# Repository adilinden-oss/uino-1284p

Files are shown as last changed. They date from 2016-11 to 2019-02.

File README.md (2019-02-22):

## \*uino-1284p 

\*uino-1284p is an Arduino compatible platform based on the Atmel ATmega1284P-AU microcontroller.

### Licensing

This work is licensed under a Creative Commons Attribution-ShareAlike 3.0 Unported License, CC BY-SA.

You are free to copy, distribute and transmit the work. You must attribute the work in the manner specified by the author or licensor (but not in any way that suggests that they endorse you or your use of the work). you alter, transform, or build upon this work, you may distribute the resulting work only under the same or similar license to this one.  

Please refer to [http://creativecommons.org/licenses/by-sa/3.0/] for the license.

### Credit

The \*uino-1284p is derived from previous work done by:

- The Arduino team <http://arduino.cc/>

### Details

The \*uino-1284p board utilizes the ATmega1284P microcontroller. The main goal of this project is to be able to access more memory, both FLASH and RAM, while keeping the Arduino UNO compatible board size and I/O assignments.

The ATmega1284P provides 128k of FLASH and 16k of RAM. It has 10 more I/O pins then the ATmega328P. The additional I/O pins are brought out to a 5x2 header in a non-standard Arduino position. The extra header pins are :

        L1/D16  o|o  L2/D17
           D18  o|o  D19
           D20  o|o  D21
           D22  o|o  D23
        D24/A6  o|o  D25/A7

The design features a dedicated ATmega8U2 for USB connectivity. The circuit has been taken from the Arduino UNO but the TQFP-32 package was chosen for easy solderability.

Power supply input for the board is selected via a jumper. Power supply options are USB bus powered or unregulated DC input. An onboard LDO regulator will accept an unregulated input voltage between 6.4V and 15V.

### Arduino

The board is supported in Arduino IDE 1.6.x via the core files available at: [adilinden-oss/uino-arduino](https://github.com/adilinden-oss/uino-arduino)

To install clone uino-arduino into the hardware folder inside your Sketchbook folder. The board will then automagically appear in the Boards menu.

### Pin Mapping

```
*uino     ATmega1284p                     Function
A0  D26   32 - PA5 (PCINT5/ADC5)
A1  D27   33 - PA4 (PCINT4/ADC4)
A2  D28   34 - PA3 (PCINT3/ADC3)
A3  D29   35 - PA2 (PCINT2/ADC2)
A4  D30   36 - PA1 (PCINT1/ADC1)
A5  D31   37 - PA0 (PCINT0/ADC0)

D0        9  - PD0 (PCINT24/RXD0/T3)      UART RX0
D1        10 - PD1 (PCINT25/TXD0)         UART TX0
D2        11 - PD2 (PCINT26/RXD1/INT0)    IRQ2, UART RX1
D3        12 - PD3 (PCINT27/TXD1/INT1)    IRQ3, UART TX1
D4        13 - PD4 (PCINT28/XCK1/OC1B)    PWM
D5        14 - PD5 (PCINT29/OC1A)         PWM
D6        15 - PD6 (PCINT30/OC2B/ICP)     PWM
D7        16 - PD7 (PCINT31/OC2A)         PWM

D8        42 - PB2 (PCINT10/INT2/AIN0)  
D9        43 - PB3 (PCINT11/OC0A/AIN1)    PWM
D10       44 - PB4 (PCINT12/OC0B/SS)      PWM, SPI SS
D11       1  - PB5 (PCINT13/ICP3/MOSI)    SPI MOSI
D12       2  - PB6 (PCINT14/OC3A/MISO)    PWM, SPI MISO
D13       3  - PB7 (PCINT15/OC3B/SCK)     PWM, SPI SCK, LED

SCL D14   19 - PC0 (PCINT16/SCL)          SCL
SDA D15   20 - PC1 (PCINT17/SDA)          SDA
L1  D16   21 - PC2 (PCINT18/TCK)          L1
L2  D17   22 - PC3 (PCINT19/TMS)          L2

D18       23 - PC4 (PCINT20/TDO)
D19       24 - PC5 (PCINT21/TDI)
D20       25 - PC6 (PCINT22/TOSC1)
D21       26 - PC7 (PCINT23/TOSC2)
D22       40 - PB0 (PCINT8/T0/XCK0)
D23       41 - PB1 (PCINT9/T1/CLK0)
A6  D24   30 - PA7 (PCINT7/ADC7)
A7  D25   31 - PA6 (PCINT6/ADC6)
```

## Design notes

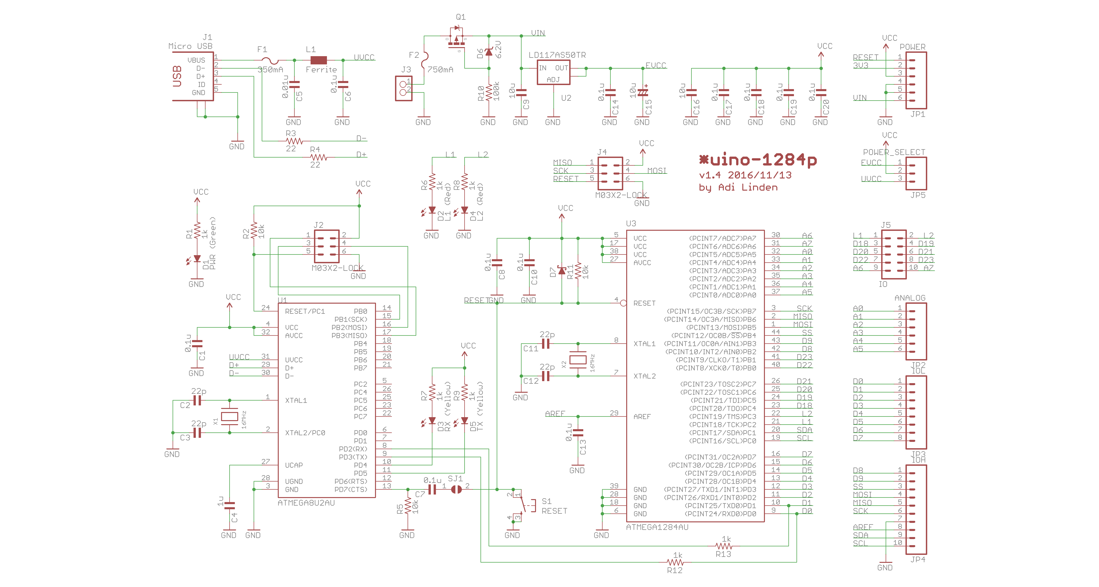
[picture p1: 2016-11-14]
uino-1284p-sch.png

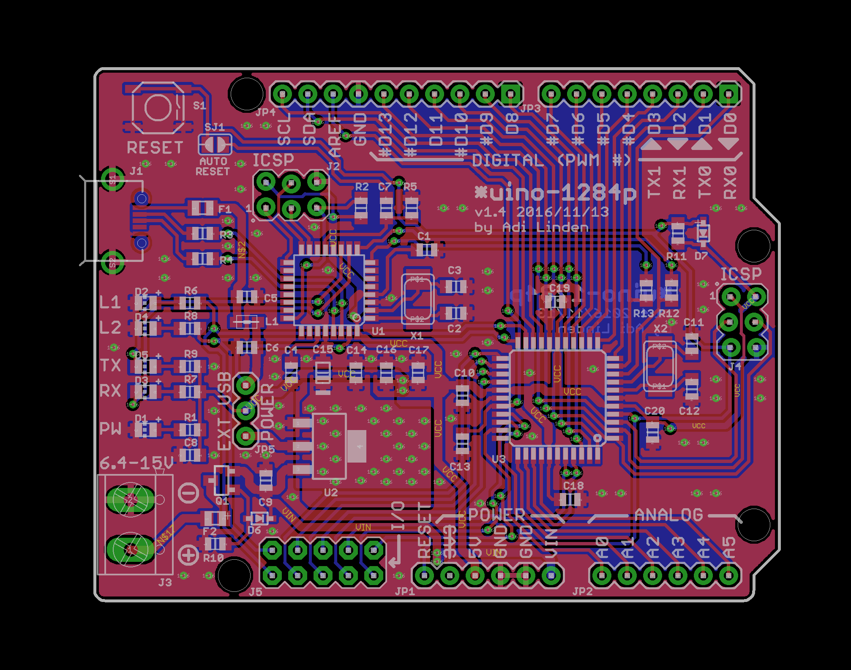
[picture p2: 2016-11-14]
uino-1284p-brd.png

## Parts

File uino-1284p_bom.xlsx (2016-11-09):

Part | Quantity | Value | Manufacturer Part Number | DigiKey Part Number | Package | Description
C1, C6, C7, C8, C10, C13, C14, C17, C18, C19, C20 | 11 | 0.1u | CL21B104KBFNNNG | 1276-6468-1-ND | C0805 | 0.10µF ±10% 50V Ceramic Capacitor X7R 0805 (2012 Metric)
C2, C3, C11, C12 | 4 | 22p | CL21C220JBANNNC | 1276-1047-1-ND | C0805 | 22pF ±5% 50V Ceramic Capacitor C0G, NP0 0805 (2012 Metric)
C4 | 1 | 1u | CL21B105KOFNNNG | 1276-6471-1-ND | C0805 | 1µF ±10% 16V Ceramic Capacitor X7R 0805 (2012 Metric)
C5 | 1 | 0.01u | CL21B103KBANNNC | 1276-1015-1-ND | C0805 | 10000pF ±10% 50V Ceramic Capacitor X7R 0805 (2012 Metric)
C9, C16 | 2 | 10u | CL21A106KOQNNNG | 1276-6455-1-ND | C0805 | 10µF ±10% 16V Ceramic Capacitor X5R 0805 (2012 Metric)
C15 | 1 | 10u | F920J106MPA | 478-8115-1-ND | C0805 | 10µF ±20% Molded Tantalum Capacitors 6.3V 0805 (2012 Metric) 6 Ohm
D1 | 1 | 6.2V Zener | DZ2J062M0L | DZ2J062M0LCT-ND | SOD323 | Zener Diode 6.2V 200mW ±5% Surface Mount SMini2-F5-B
D2 | 1 | 1A Schottky | DB2J31700LCT-ND | DB2J31700L | SOD323 | Diode Schottky 30V 1A Surface Mount SMini2-F5-B
F1 | 1 | 350mA | 0ZCK0035FF2G | 507-1812-1-ND | R0805 | PTC Resettable Fuse 6V 350mA Ih Surface Mount 0805 (2012 Metric), Concave
F2 | 1 | 750mA | 0ZCK0075FF2E | 507-1814-1-ND | R0805 | PTC Resettable Fuse 6V 750mA Ih Surface Mount 0805 (2012 Metric), Concave
J1 | 1 | Micro USB | 475890001 | WM17143CT-ND | ZX62D-AB-5P8 | USB - micro AB Receptacle Connector 5 Position Surface Mount, Right Angle, Horizontal
J2, J4 | 2 | Header 2x3 | M20-9980345 | 952-2120-ND | 2X03 | 6 Positions Header, Unshrouded, Breakaway Connector 0.100" (2.54mm) Through Hole Gold
J3 | 1 | Terminal | OSTTC022162 | ED2609-ND | 7.6x10.16mm | 2 Position Wire to Board Terminal Block Horizontal with Board 0.200" (5.08mm) Through Hole
J5 | 1 | Header 2x5 | PPTC052LFBN-RC | S6105-ND | 2X05 | 10 Position Header Connector 0.100" (2.54mm) Through Hole Tin
JP1, JP2 | 2 | Header 1x6 | PPTC061LFBN-RC | S7004-ND | 1X06 | 6 Position Header Connector 0.100" (2.54mm) Through Hole Tin
JP3 | 1 | Header 1x8 | PPTC081LFBN-RC | S7006-ND | 1X08 | 8 Position Header Connector 0.100" (2.54mm) Through Hole Tin
JP4 | 1 | Header 1x10 | PPTC101LFBN-RC | S7008-ND | 1X10 | 10 Position Header Connector 0.100" (2.54mm) Through Hole Tin
JP5 | 1 | Header 1x3 | M20-9990345 | 952-2263-ND | 1X03 | Header 3
L1 | 1 | Ferrite | MI0805K400R-10 | 240-2389-1-ND | L0805 | FERRITE BEAD 40 OHM 0805 1LN
LED1 | 1 | PWR (Green) | LTST-S220KGKT | 160-1468-1-ND | CHIP-LED0805 | Green 568nm LED Indication - Discrete 2V 0805 (2012 Metric)
LED2, LED4 | 2 | L1 (Red) | LTST-S220KRKT | 160-1469-1-ND | CHIP-LED0805 | Red 631nm LED Indication - Discrete 2V 0805 (2012 Metric)
LED3, LED5 | 2 | RX (Yellow) | LTST-S220KSKT | 160-1470-1-ND | CHIP-LED0805 | Yellow 589nm LED Indication - Discrete 2V 0805 (2012 Metric)
Q1 | 1 | P-FET | IRLML2244TRPBF | IRLML2244TRPBFCT-ND | SOT23 | MOSFET P-CH 20V 4.3A SOT23
R1, R6, R7, R8, R9, R12, R13 | 7 | 1k | RC0805JR-071KL | 311-1.0KARCT-ND | R0805 | RES SMD 1K OHM 5% 1/8W 0805
R2, R5, R11 | 3 | 10k | RC0805JR-0710KL | 311-10KARCT-ND | R0805 | RES SMD 10K OHM 5% 1/8W 0805
R3, R4 | 2 | 22 | RC0805JR-0722RL | 311-22ARCT-ND | R0805 | RES SMD 22 OHM 5% 1/8W 0805
R10 | 1 | 100k | RC0805JR-07100KL | 311-100KARCT-ND | R0805 | RES SMD 100K OHM 5% 1/8W 0805
S1 | 1 | RESET | TL3305AF160QG | EG5350CT-ND | 4.50x4.50mm | Tactile Switch SPST-NO Top Actuated Surface Mount
U1 | 1 | ATMEGA8U2AU | ATMEGA8U2-AUR | ATMEGA8U2-AURCT-ND | TQFP32-08 | Atmel 8-bit Microcontroller with 8/16/32K Bystes of ISP Flash and USB Controller. ATmega8U2, ATmega16U2, and ATmega32U2
U2 | 1 | LD1117S50 | AZ1117IH-5.0TRG1 | AZ1117IH-5.0TRG1DICT-ND | SOT223 | Voltage Regulator LM1117
U3 | 1 | ATMEGA1284AU | ATMEGA1284P-AUR | ATMEGA1284P-AURCT-ND | TQFP44 | 8-bit Microcontroller with 64K Bytes In-System Programmable Flash
X1, X2 | 2 | 16MHz | NX5032GA-16.000000MHZ-LN-CD-1 | 644-1037-1-ND | NX5032 | Low cost SMT crystals, no capacitors included

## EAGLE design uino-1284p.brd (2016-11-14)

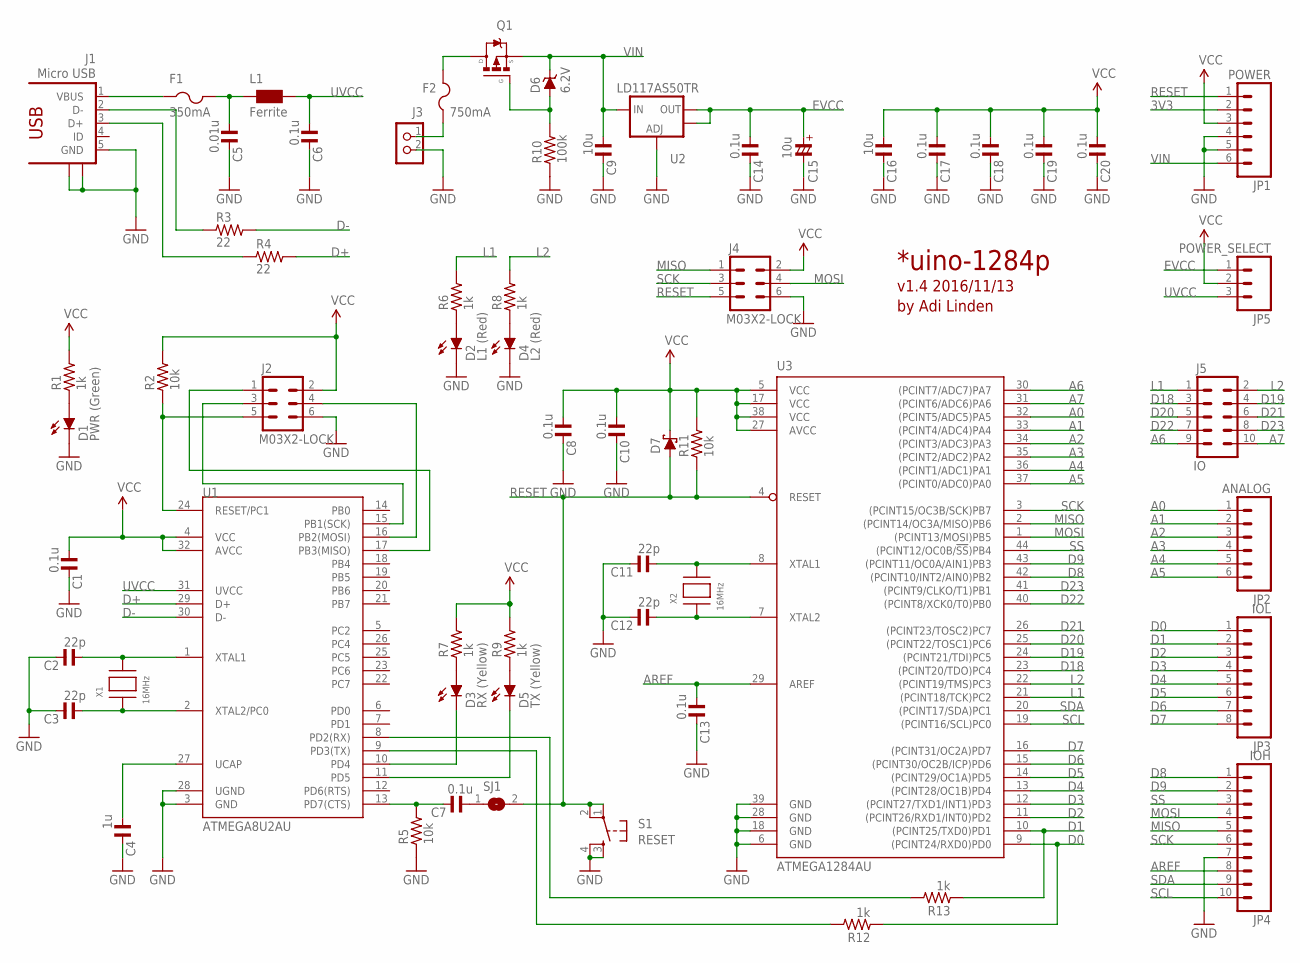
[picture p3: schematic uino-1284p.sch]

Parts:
C1, C6, C7, C8, C10, C13, C14, C17, C18, C19, C20: 0.1u; C0805MP
C2, C3, C11, C12: 22p; C0805MP
C4: 1u; C0805MP
C5: 0.01u; C0805MP
C9, C16: 10u; C0805MP
C15: 10u; C0805MP/T
D1: PWR (Green); CHIP-LED0805MP
D2: L1 (Red); CHIP-LED0805MP
D3: RX (Yellow); CHIP-LED0805MP
D4: L2 (Red); CHIP-LED0805MP
D5: TX (Yellow); CHIP-LED0805MP
D6: 6.2V; SOD323
D7: SCHOTTKY-DIODESOD323; SOD323
F1: 350mA; R0805
F2: 750mA; R0805
J1: Micro USB; ZX62D-AB-5P8
J2, J4: M03X2-LOCK; 2X03_LOCK
J3: CON_TERMINAL_BLOCK_02-5MM; TERMINAL_BLOCK_2P_5
J5: IO; 2X05
JP1: POWER; 1X06
JP2: ANALOG; 1X06
JP3: IOL; 1X08
JP4: IOH; 1X10
JP5: POWER_SELECT; 1X03
L1: Ferrite; 0805
Q1: MMBF0202PLT1; SOT23
R1, R6, R7, R8, R9, R12, R13: 1k; R0805MP
R2, R5, R11: 10k; R0805MP
R3, R4: 22; R0805MP
R10: 100k; R0805MP
S1: RESET; TACTILE_SWITCH_SMD
SJ1: SJ
U1: ATMEGA8U2AU; TQFP32-08
U2: LD117AS50TR; SOT223
U3: ATMEGA1284AU; TQFP44
X1, X2: 16MHz; NX5032

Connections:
3V3: JP1.2
A0: JP2.1, U3.32 ((PCINT5/ADC5)PA5)
A1: JP2.2, U3.33 ((PCINT4/ADC4)PA4)
A2: JP2.3, U3.34 ((PCINT3/ADC3)PA3)
A3: JP2.4, U3.35 ((PCINT2/ADC2)PA2)
A4: JP2.5, U3.36 ((PCINT1/ADC1)PA1)
A5: JP2.6, U3.37 ((PCINT0/ADC0)PA0)
A6: J5.9, U3.30 ((PCINT7/ADC7)PA7)
A7: J5.10, U3.31 ((PCINT6/ADC6)PA6)
AREF: C13.1, JP4.8, U3.29 (AREF)
D0: JP3.1, R12.1, U3.9 ((PCINT24/RXD0)PD0)
D1: JP3.2, R13.1, U3.10 ((PCINT25/TXD0)PD1)
D2: JP3.3, U3.11 ((PCINT26/RXD1/INT0)PD2)
D3: JP3.4, U3.12 ((PCINT27/TXD1/INT1)PD3)
D4: JP3.5, U3.13 ((PCINT28/OC1B)PD4)
D5: JP3.6, U3.14 ((PCINT29/OC1A)PD5)
D6: JP3.7, U3.15 ((PCINT30/OC2B/ICP)PD6)
D7: JP3.8, U3.16 ((PCINT31/OC2A)PD7)
D8: JP4.1, U3.42 ((PCINT10/INT2/AIN0)PB2)
D9: JP4.2, U3.43 ((PCINT11/OC0A/AIN1)PB3)
D18: J5.3, U3.23 ((PCINT20/TDO)PC4)
D19: J5.4, U3.24 ((PCINT21/TDI)PC5)
D20: J5.5, U3.25 ((PCINT22/TOSC1)PC6)
D21: J5.6, U3.26 ((PCINT23/TOSC2)PC7)
D22: J5.7, U3.40 ((PCINT8/XCK0/T0)PB0)
D23: J5.8, U3.41 ((PCINT9/CLKO/T1)PB1)
D+: R4.2, U1.29 (D+)
D-: R3.2, U1.30 (D-)
EVCC: C14.1, C15.+, JP5.1, U2.2 (OUT), U2.4 (OUT)
GND: C1.2, C2.2, C3.2, C4.2, C5.2, C6.2, C8.2, C9.2, C10.2, C11.2, C12.2, C13.2, C14.2, C15.-, C16.2, C17.2, C18.2, C19.2, C20.2, D1.C, D2.C, D4.C, J1.5 (GND), J1.S1, J1.S2, J2.6, J3.2, J4.6, JP1.4, JP1.5, JP4.7, R5.1, R10.1, S1.3, S1.4, U1.3 (GND), U1.28 (UGND), U2.1 (ADJ), U3.6 (GND), U3.18 (GND), U3.28 (GND), U3.39 (GND)
L1: J5.1, R6.2, U3.21 ((PCINT18/TCK)PC2)
L2: J5.2, R8.2, U3.22 ((PCINT19/TMS)PC3)
MISO: J4.1, JP4.5, U3.2 ((PCINT14/OC3A/MISO)PB6)
MOSI: J4.4, JP4.4, U3.1 ((PCINT13/MOSI)PB5)
unnamed: F2.2, Q1.3 (D)
unnamed: C5.1, F1.2, L1.1
unnamed: C7.1, SJ1.1
unnamed: J1.2 (D-), R3.1
unnamed: J1.3 (D+), R4.1
unnamed: R12.2, U1.9 (PD3(TX))
unnamed: R13.2, U1.8 (PD2(RX))
unnamed: C2.1, U1.1 (XTAL1), X1.P$2
unnamed: C3.1, U1.2 (XTAL2/PC0), X1.P$1
unnamed: C4.1, U1.27 (UCAP)
unnamed: D2.A, R6.1
unnamed: D4.A, R8.1
unnamed: J2.1, U1.17 (PB3(MISO))
unnamed: J2.3, U1.15 (PB1(SCK))
unnamed: J2.5, R2.1, U1.24 (RESET/PC1)
unnamed: J2.4, U1.16 (PB2(MOSI))
unnamed: F2.1, J3.1
unnamed: D6.A, Q1.1 (G), R10.2
unnamed: C11.1, U3.8 (XTAL1), X2.P$2
unnamed: C12.1, U3.7 (XTAL2), X2.P$1
unnamed: D3.A, R7.1
unnamed: D5.A, R9.1
unnamed: D3.C, U1.10 (PD4)
unnamed: D5.C, U1.11 (PD5)
unnamed: C7.2, R5.2, U1.13 (PD7(CTS))
unnamed: D1.A, R1.1
RESET: D7.A, J4.5, JP1.1, R11.1, S1.1, S1.2, SJ1.2, U3.4 (RESET)
SCK: J4.3, JP4.6, U3.3 ((PCINT15/OC3B/SCK)PB7)
SCL: JP4.10, U3.19 ((PCINT16/SCL)PC0)
SDA: JP4.9, U3.20 ((PCINT17/SDA)PC1)
SS: JP4.3, U3.44 ((PCINT12/OC0B/!SS!)PB4)
UVCC: C6.1, JP5.3, L1.2, U1.31 (UVCC)
VBUS: F1.1, J1.1 (VBUS)
VCC: C1.1, C8.1, C10.1, C16.1, C17.1, C18.1, C19.1, C20.1, D7.C, J2.2, J4.2, JP1.3, JP5.2, R1.2, R2.2, R7.2, R9.2, R11.2, U1.4 (VCC), U1.32 (AVCC), U3.5 (VCC), U3.17 (VCC), U3.27 (AVCC), U3.38 (VCC)
VIN: C9.1, D6.C, JP1.6, Q1.2 (S), U2.3 (IN)

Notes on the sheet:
*uino-1284p
v1.4 2016/11/13
by Adi Linden

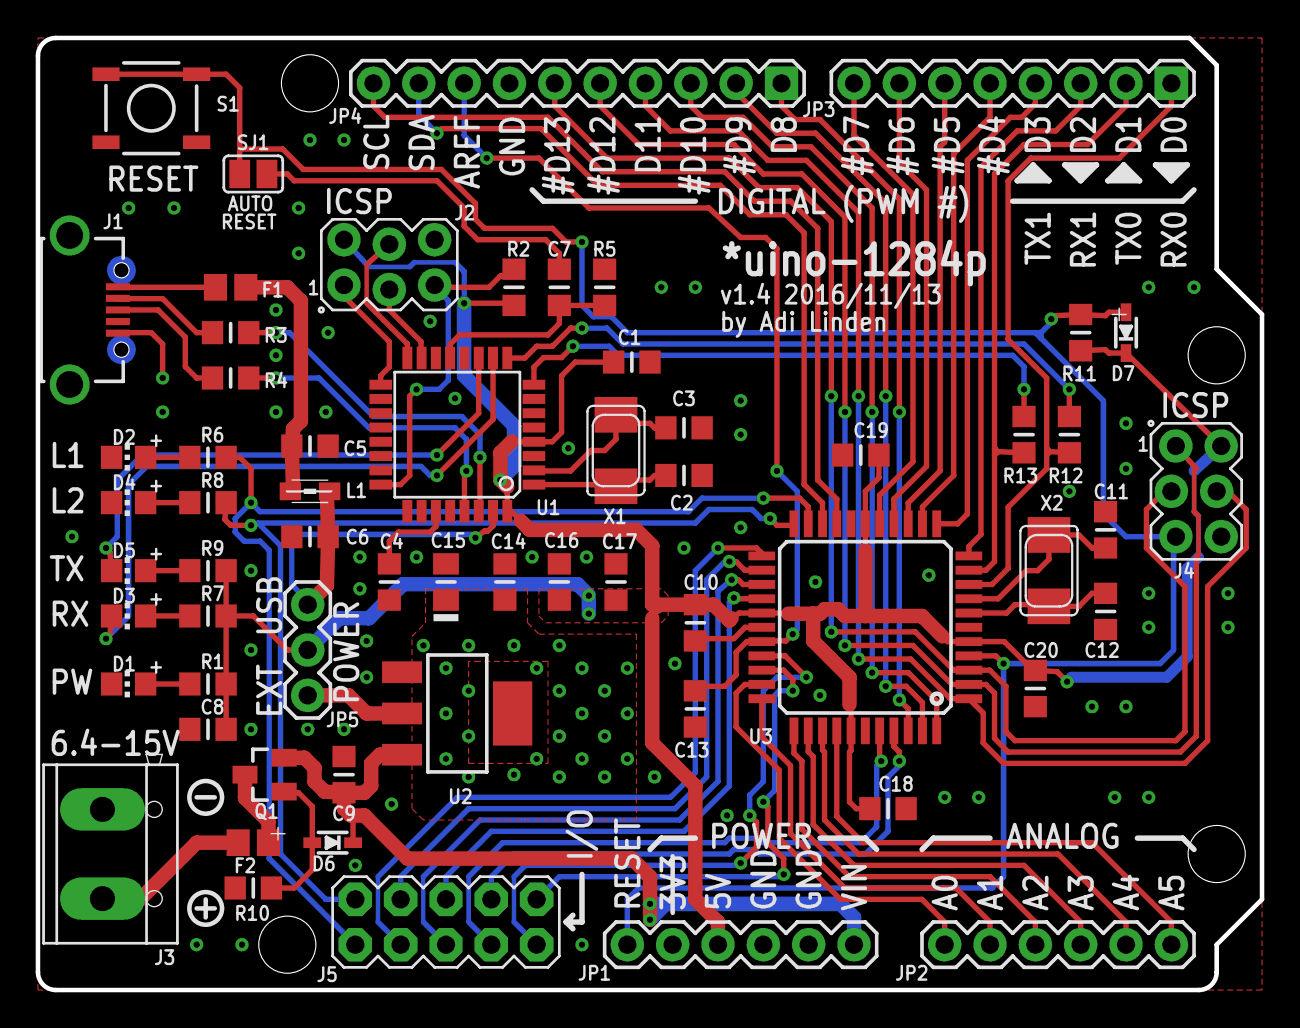
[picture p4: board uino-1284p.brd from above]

Board: 2 copper layers, 68.6 x 53.3 mm, 61 parts (0 on the bottom side), 68 nets.

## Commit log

2011-12-30 Completed the board layout. Completed silk screen.
    [uino-1284p.brd, uino-1284p.sch]
2011-12-30 Added several files.
    Added board, schematic and Gerber files for v0.2.
    Added PNG for v0.2.
2011-12-31 Updated to v0.3.
    - Added 5x2 header to make additional I/O available.
    - Replaced shottky diode on USB supply with jumper for input
    supply voltage selection.
    [uino-1284p.brd, uino-1284p.sch]
2011-12-31 Added pin assignment for v0.3
2016-10-17 Updated pin mapping. Added reference to Arduino files.
2016-10-19 Changed net labels to match uino-arduino core board definitions.
    [uino-1284p.brd, uino-1284p.sch]
2016-10-31 Refactor to place eagle files into root.
    [uino-1284p.brd, uino-1284p.sch]
2016-11-04 Unified device name text on board. Arranged name labels.
    [uino-1284p.brd, uino-1284p.sch]
2016-11-04 Changed to micro USB. Moved USB ICSP header.
    [uino-1284p.brd, uino-1284p.sch]
2016-11-04 Fixed LED names and placements.
    [uino-1284p.brd]
2016-11-05 Made prefix for IC consistent.
    [uino-1284p.brd, uino-1284p.sch]
2016-11-05 Moved VCC lines. Fixed more naming.
    [uino-1284p.brd, uino-1284p.sch]
2016-11-05 Added BOM.
    [uino-1284p_bom.xls]
2016-11-05 Changed power input jack to screw terminal.
    [uino-1284p.brd, uino-1284p.sch]
2016-11-05 Renamed power jack.
    [uino-1284p.brd, uino-1284p.sch]
2016-11-05 Updated BOM.
    [uino-1284p_bom.xls]
2016-11-05 Changed power jack orientation.
    [uino-1284p.brd, uino-1284p.sch]
2016-11-05 Added quantity column in BOM.
    [uino-1284p_bom.xls]
2016-11-07 Increased text sizes. Optimized polygon fills and routing.
    [uino-1284p.brd, uino-1284p.sch]
2016-11-07 Fixed some labels.
    [uino-1284p.brd]
2016-11-08 Board image with polygons filled.
2016-11-09 Replaced reverse polarity schottky with P-FET.
    [uino-1284p.brd, uino-1284p.sch]
2016-11-09 Fixed values and numbering.
    [uino-1284p.brd, uino-1284p.sch]
2016-11-09 Changed tantalum to 0805 and ceramic. Made use of extra space.
    [uino-1284p.brd, uino-1284p.sch, uino-1284p_bom.xls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]
2016-11-09 Corrected X2 and J2 label.
    [uino-1284p.brd]
2016-11-13 Added polygon to have voltage regulator without thermals for better heat sinking.
    [uino-1284p.brd, uino-1284p.sch]
2016-11-14 Changed ISP header to offset style making use of permanent header optional (hopefully).
    [uino-1284p.brd, uino-1284p.sch]
2016-11-14 Version 1.4.
    [uino-1284p.brd, uino-1284p.sch]

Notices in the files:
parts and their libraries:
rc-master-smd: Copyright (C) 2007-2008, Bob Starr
